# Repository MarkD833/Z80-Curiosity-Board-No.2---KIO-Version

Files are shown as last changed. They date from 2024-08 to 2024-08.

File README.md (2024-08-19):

# Zilog Z80 Curiosity Board #2 - The KIO Version

After my attempt to build a Z80 board met with reasonable success, I set my sights on a possible RetroDuino-Z80 board. This design is the pathfinder project with that goal in mind.

I wanted to have serial, parallel I/O and timer capability but aware of the space limitations, I decided to investigate the use of the Zilog Z80 KIO chip, or Z84C90 KIO as it's called.

This is a beast of a chip. It comes in a PLCC84 package which requires a big chunk of board space. The KIO combines the PIO, SIO  and CTC chips into one package.

The design still makes use of the PLCC44 Z80 CPU that I used previously.

## Description

The aim of this project is to provide the groundwork for a possible RetroDuino-Z80 board along the lines of my [RetroDuino-8085](https://github.com/MarkD833/RetroDuino-8085) board.

I'm hoping that this design can also run CP/M and I will be using Grant Searles excellent [web page](http://searle.x10host.com/cpm/index.html) as my starting point.

## Design

The design is fairly straightforward, using a 128Kb SRAM from my stash as well as a 64Kb EEPROM for non volatile storage. Only the lower 64Kb of SRAM is currently accessible.

I studied other designs that I came across and liked a concept that I came across whereby on startup, the whole of the ROM was copied into RAM and then the ROM disabled. The hardware was configured so that the ROM and the RAM both occupied the same 64Kb, but initially any read accessed would go to the ROM and any write accesses would go to the RAM. Once the ROM was copied into RAM (at the same addresses), the ROM would be disabled giving full read/write access to the RAM and the Z80 would continue to execute instructions as if nothing had happened.

The design uses simple logic chips to handle the address decoding, as well as the disabling of the ROM etc.

# The board layout

This is an annotated 3D view of the board generated by Kicad as it stands at v1.0.

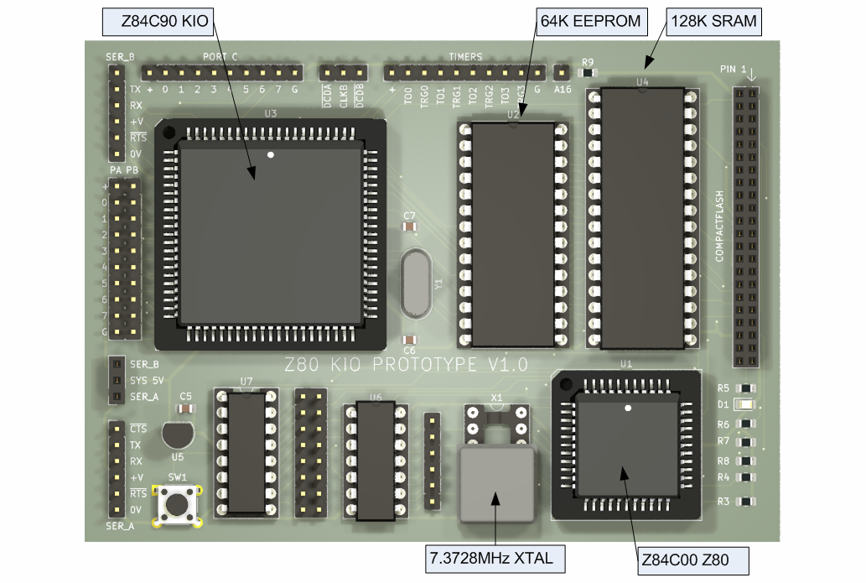
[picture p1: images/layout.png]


# Software

I adapted Dave Dunfields MONZ80 monitor program to work with this board. MONZ80 can be found on [Dave's website](https://dunfield.themindfactory.com/dnldsrc.htm) as part of the MONITORS.ZIP file. There is no documentation for the monitor but most of the commands are self explanatory.

The monitor code needs a slight tweek to reflect the address of the SIO registers within the KIO chip. My modified version of MONZ80 is in the code folder and has been edited to allow assembly using the free online assembler at [ASM80.COM](https://asm80.com) - select the Z80 CPU.

The code folder includes the assembler files to run CP/M from [Grant Searles web site](http://searle.x10host.com/cpm/index.html) but configured to assemble using the ASM80 online assembler. I've also included my instructions for loading CP/M onto the board, which are almost identical to Grants instructions.

# Known errors

* Nothing so far. 

# Conclusions

The board works as I had hoped it would. I need to develop routines for software SPI and also software I2C.

## License

This project is licensed under the GNU General Public License v3.0 - see the LICENSE.md file for details

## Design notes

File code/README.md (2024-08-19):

# Zilog Z80 Curiosity Board #2 - The KIO Version : Software

## The Z80 Monitor 
The MONZ80-RAM.ASM file contains a modified version of the excellent Z80 monitor called MONZ80 written by [Dave Dunfield](https://dunfield.themindfactory.com/). You can find the source code to the Z80 monitor along with monitors for other micros in the MONITORS.ZIP file on Dave's website. The monitor code needs a slight tweek to reflect the addresses of the SIO registers within the KIO chip. There's additional code to setup the KIO, handle the copying of the ROM into RAM and the disabling of the ROM.

MONZ80 can be assembled using the free online assembler at [ASM80.COM](https://asm80.com) - select the Z80 CPU.

I've not managed to locate a user manual for MONZ80 so I have included the user manual for MON85 as a guide to MONZ80.

# The Monitor and BASIC v4.7

## The Monitor (monitor.asm)

The simple monitor program is essentially Grants monitor program but modified to take into account the different addresses of the CompactFlash and SIO registers in my design. The monitor also copies itself into RAM and disables the ROM. The baud rate is also set to 57600 baud (rather than 115200 baud).

The main change is the use of SIO channel B. My Z80 KIO curiosity board doesn't have a hard wired clock into the SIO channel B TxCLKB & RxCLKB pins. Without a clock on TxCLKB, any byte in the TxB register will stay there forever and any code that waits for the Tx Buffer Empty bit to clear will hang forever.

As a result of this, the code expects a terminal connection on SIO channel A. I've added a constant called USE_SIOB which can be set to 0 to ignore SIO channel B or set to a 1 to also use SIO channel B. Setting USE_SIOB to a 1 will let the code detect a terminal on either SIO channel.

There are also some hard coded values that tell the monitor where to find BASIC. I've added a new value called BASSIZE which is the rough amount of ROM space that BASIC occupies. It is only needed when copying BASIC from ROM to RAM and I've set it to $2000.
 
## BASIC v4.7 (basic.asm)

The banner for this version of BASIC says that it is Z80 BASIC Ver 4.7b (c) 1978 by Microsoft. The assembler source has the phrase "NASCOM ROM BASIC Ver 4.7, (C) 1978 Microsoft".

I've modified this version of BASIC so that it can be assembled using ASM80. Other than that, the code is identical.

The Intel-Hex file can be programmed into the ROM at the same time as the monitor or it can be loaded into RAM using the monitor. 

# Installing CP/M

These are my notes for loading CP/M onto the board, which are almost identical to Grants instructions and include any modifications I may have done to his code.

## Step 1 - Formatting the CompactFlash drive

The formatting of the CompactFlash drive is done using the file FORM128.ASM (for 128Mb or larger CompactFlash cards). I've modified the CompactFlash registers to suit my KIO board and changed the directives so that the code can be assembled using ASM80.

Use the monitor to load the FORM128.HEX file and type G5000 to execute the code. The formatter should report back that it has created and formatted drives A to P.

## Step 2 - Installing CP/M

Installing CP/M involves 3 separate files: CP/M itself (CPM22.ASM), the CP/M BIOS (CBIOS128.ASM) and a small program to copy CP/M and the CP/M BIOS onto the CompactFlash card (PUTSYS.ASM).

* The CPM22.ASM file has been edited to change the directives so that the code can be assembled using ASM80.
* The CBIOS128.ASM file has been modified so the CompactFlash registers and SIO registers are correct for my KIO board. Directives have also been altered so that the code can be assembled using ASM80.
* The PUTSYS.ASM file has been modified so the CompactFlash registers are correct for my KIO board. Directives have also been altered so that the code can be assembled using ASM80.

Once the 3 files have been assembled, load each in turn from the monitor prompt. Then type G5000 to execute the PUTSYS program. This will copy CP/M and the CBIOS onto the CompactFlash card.

CP/M is now installed on the CompactFlash card. Reset the board and from the monitor prompt type X to boot CP/M, answering Y to the Boot CP/M prompt.

## Step 3 - Installing the downloader.

In order to transfer files to the CP/M system, a small application called DOWNLOAD.COM needs to be installed on the CP/M A: drive.

First, load CP/M off the CompactFlash card (X then Y in the monitor) and then reset the board. CP/M and the CBIOS are still in memory.

Download the file DOWNLOAD2.HEX. This file will be loaded into memory at address $4100. Then type GFFE8. This will execute a small piece of code that is part of the CBIOS. It will copy DOWNLOAD2.HEX from $4100 to $0100 and the run CP/M that is already in memory.

When the A> prompt appears, type SAVE 2 DOWNLOAD.COM. This will save 2 pages (2x 256 byte blocks, or 512 bytes) of data starting at address $0100 in memory to the file DOWNLOAD.COM on the A: drive.

At the A> prompt, you can type DIR <enter> to get a directory listing of drive A. You should see the file DOWNLOAD.COM.

## Step 4 - Transferring files to the CP/M system

You can read up on Grant Seales web page on how to use his packager program.

Before transferring the packaged files to the CP/M system, make sure that your terminal is set to use RTS/CTS handshaking as the serial routines in the CBIOS will use hardware handshaking to control the flow of data.

With CP/M running, download the file pkgCPM211Files.txt. This file is a package containing several CP/M programs: LOAD.COM, PIP.COM, STAT.COM, SUBMIT.COM, DDT.COM, DISPLAY.COM, DUMP.COM, ED.COM and ASM.COM. Most of these programs are detailed in the CP/M Operating System Manual.

You can also download the file pkgMBASIC.txt. This file is the CP/M version of BASIC-80 v5.21 by Microsoft.

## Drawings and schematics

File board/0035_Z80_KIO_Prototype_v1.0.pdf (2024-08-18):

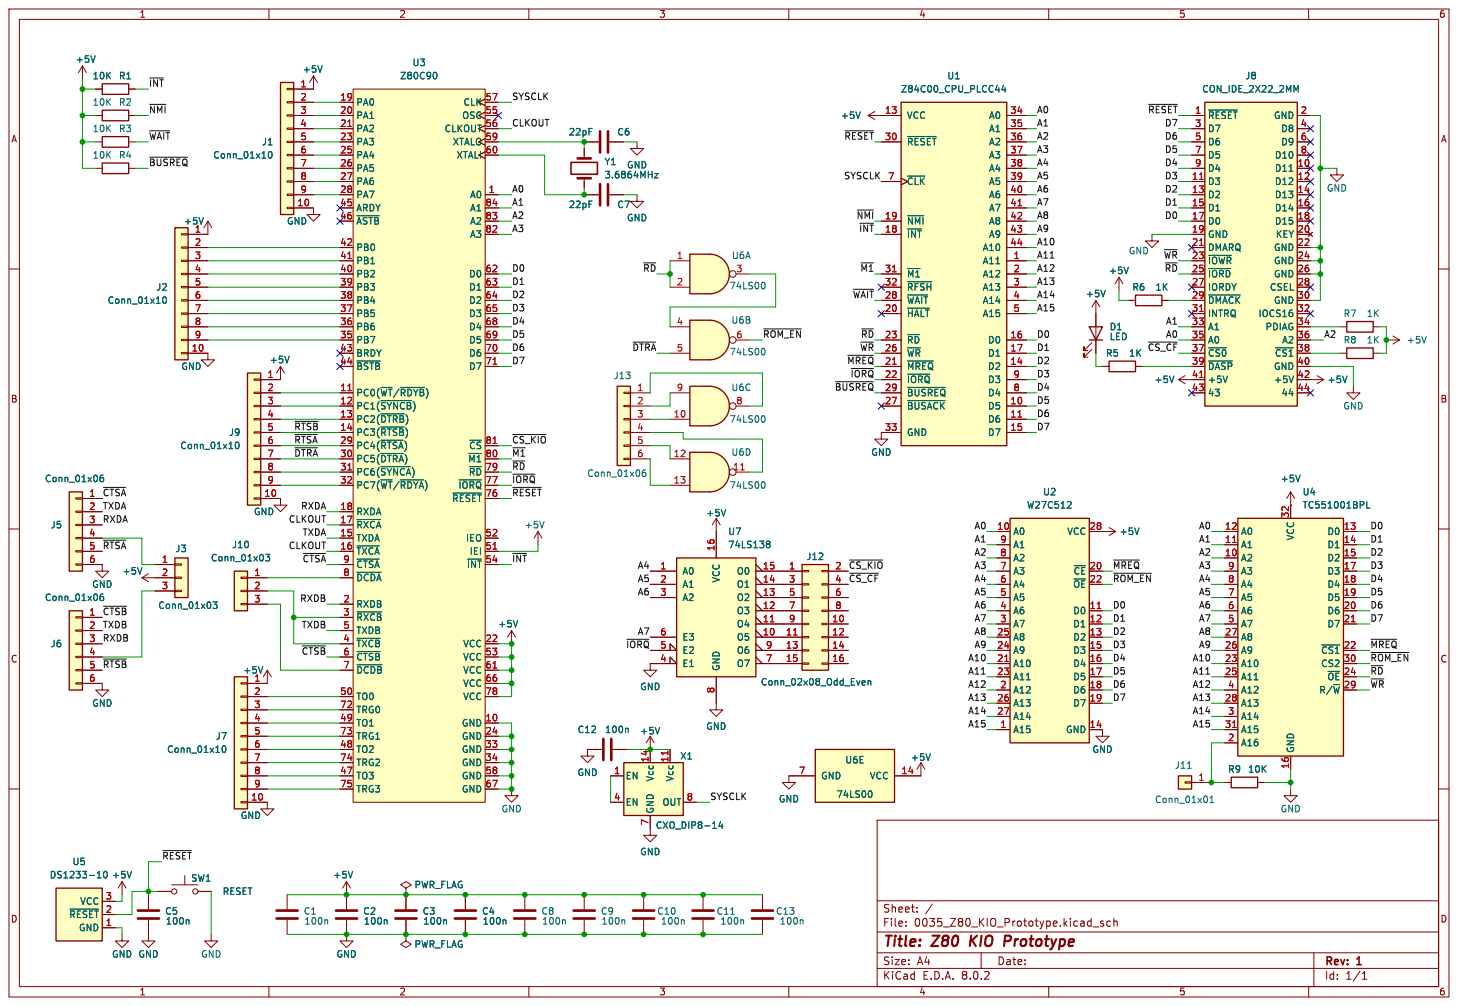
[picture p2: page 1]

File: 0035_Z80_KIO_Prototype.kicad_sch Sheet: /
Id: 1/1 Title: Z80 KIO Prototype

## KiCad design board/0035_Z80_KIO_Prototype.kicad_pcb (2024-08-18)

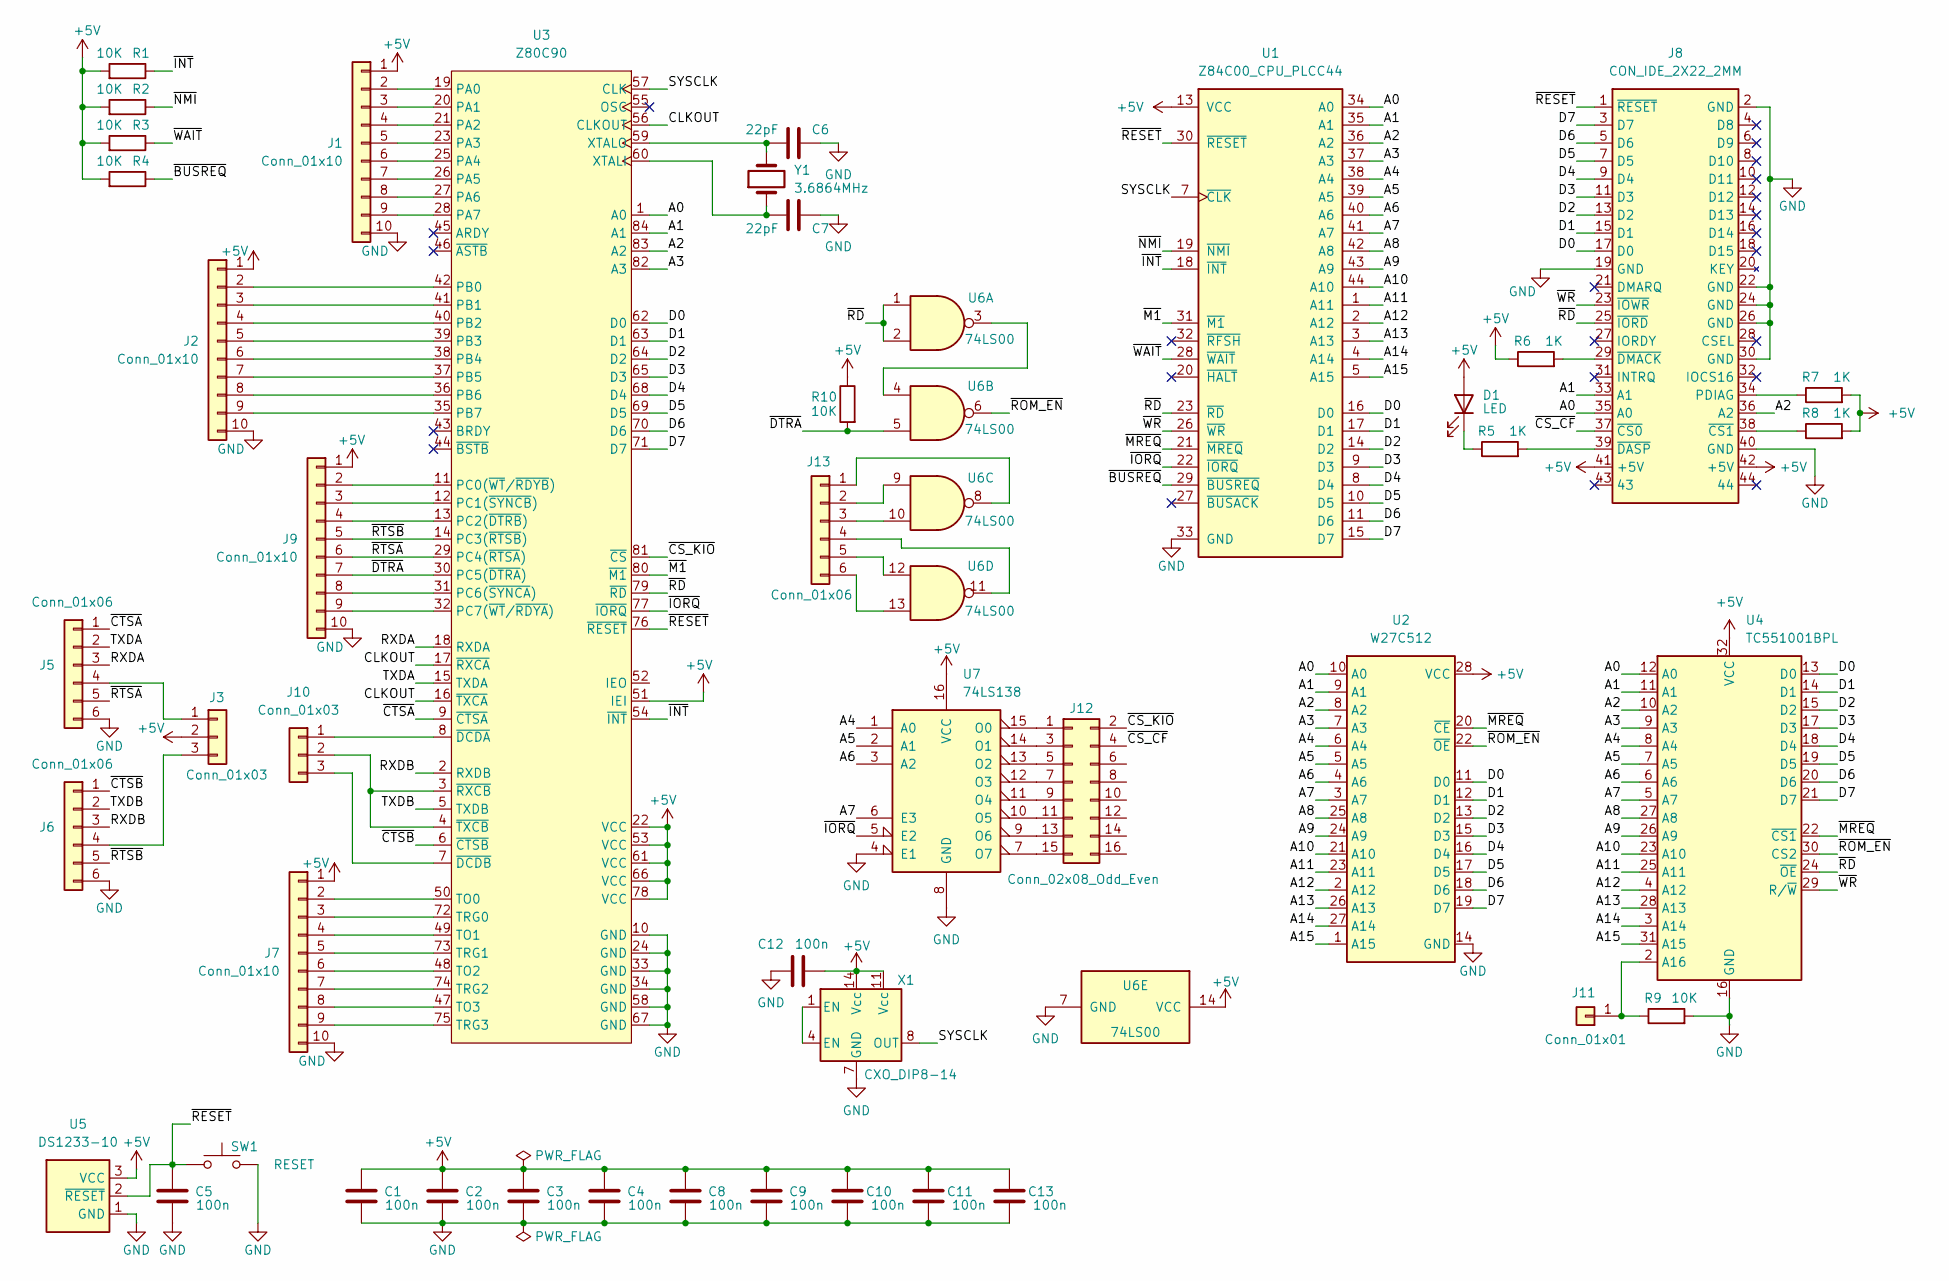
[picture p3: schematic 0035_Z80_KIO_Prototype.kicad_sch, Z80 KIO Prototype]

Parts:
C1, C2, C3, C4, C5, C8, C9, C10, C11, C12, C13: 100n; C_0805_2012Metric_Pad1.18x1.45mm_HandSolder
C6, C7: 22pF; C_0805_2012Metric_Pad1.18x1.45mm_HandSolder
D1: LED; LED_0805_2012Metric_Pad1.15x1.40mm_HandSolder
J1, J2, J7, J9: Conn_01x10; PinHeader_1x10_P2.54mm_Vertical
J3: Conn_01x03; PinSocket_1x03_P2.54mm_Vertical
J5, J6, J13: Conn_01x06; PinHeader_1x06_P2.54mm_Vertical
J8: CON_IDE_2X22_2MM; CompactFlashHeader_2x22_P2.00mm_Vertical
J10: Conn_01x03; PinHeader_1x03_P2.54mm_Vertical
J11: Conn_01x01; PinHeader_1x01_P2.54mm_Vertical
J12: Conn_02x08_Odd_Even; PinHeader_2x08_P2.54mm_Vertical
R1, R2, R3, R4, R9, R10: 10K; R_0805_2012Metric_Pad1.20x1.40mm_HandSolder
R5, R6, R7, R8: 1K; R_0805_2012Metric_Pad1.20x1.40mm_HandSolder
SW1: RESET; SW_TH_Tactile
U1: Z84C00_CPU_PLCC44; PLCC-44_THT-Socket
U2: W27C512; DIP-28_W15.24mm
U3: Z80C90; PLCC-84_THT-Socket
U4: TC551001BPL; DIP-32_W15.24mm_Socket
U5: DS1233-10; TO-92L_Inline
U6: 74LS00; DIP-14_W7.62mm_Socket
U7: 74LS138; DIP-16_W7.62mm_Socket
X1: CXO_DIP8-14; DIP-14_W7.62mm-XTAL_SOCKET
Y1: 3.6864MHz; Crystal_HC49-U_Vertical

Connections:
+5V: C1.2, C2.2, C3.2, C4.2, C8.2, C9.2, C10.2, C11.2, C12.2, C13.2, D1.2 (A), J1.1, J2.1, J3.2, J7.1, J8.41 (+5V), J8.42 (+5V), J9.1, R1.2, R2.2, R3.2, R4.2, R6.1, R7.2, R8.2, R10.1, U1.13 (VCC), U2.28 (VCC), U3.22 (VCC), U3.51 (IEI), U3.53 (VCC), U3.61 (VCC), U3.66 (VCC), U3.78 (VCC), U4.32 (VCC), U5.3 (VCC), U6.14 (VCC), U7.16 (VCC), X1.11 (Vcc), X1.14 (Vcc)
/A0: J8.35 (A0), U1.34 (A0), U2.10 (A0), U3.1 (A0), U4.12 (A0)
/A1: J8.33 (A1), U1.35 (A1), U2.9 (A1), U3.84 (A1), U4.11 (A1)
/A2: J8.36 (A2), U1.36 (A2), U2.8 (A2), U3.83 (A2), U4.10 (A2)
/A3: U1.37 (A3), U2.7 (A3), U3.82 (A3), U4.9 (A3)
/A4: U1.38 (A4), U2.6 (A4), U4.8 (A4), U7.1 (A0)
/A5: U1.39 (A5), U2.5 (A5), U4.7 (A5), U7.2 (A1)
/A6: U1.40 (A6), U2.4 (A6), U4.6 (A6), U7.3 (A2)
/A7: U1.41 (A7), U2.3 (A7), U4.5 (A7), U7.6 (E3)
/A8: U1.42 (A8), U2.25 (A8), U4.27 (A8)
/A9: U1.43 (A9), U2.24 (A9), U4.26 (A9)
/A10: U1.44 (A10), U2.21 (A10), U4.23 (A10)
/A11: U1.1 (A11), U2.23 (A11), U4.25 (A11)
/A12: U1.2 (A12), U2.2 (A12), U4.4 (A12)
/A13: U1.3 (A13), U2.26 (A13), U4.28 (A13)
/A14: U1.4 (A14), U2.27 (A14), U4.3 (A14)
/A15: U1.5 (A15), U2.1 (A15), U4.31 (A15)
/CLKOUT: U3.16 (~TXCA), U3.17 (~RXCA), U3.56 (CLKOUT)
/D0: J8.17 (D0), U1.16 (D0), U2.11 (D0), U3.62 (D0), U4.13 (D0)
/D1: J8.15 (D1), U1.17 (D1), U2.12 (D1), U3.63 (D1), U4.14 (D1)
/D2: J8.13 (D2), U1.14 (D2), U2.13 (D2), U3.64 (D2), U4.15 (D2)
/D3: J8.11 (D3), U1.9 (D3), U2.15 (D3), U3.65 (D3), U4.17 (D3)
/D4: J8.9 (D4), U1.8 (D4), U2.16 (D4), U3.68 (D4), U4.18 (D4)
/D5: J8.7 (D5), U1.10 (D5), U2.17 (D5), U3.69 (D5), U4.19 (D5)
/D6: J8.5 (D6), U1.11 (D6), U2.18 (D6), U3.70 (D6), U4.20 (D6)
/D7: J8.3 (D7), U1.15 (D7), U2.19 (D7), U3.71 (D7), U4.21 (D7)
/RXDA: J5.3, U3.18 (RXDA)
/RXDB: J6.3, U3.2 (RXDB)
/SYSCLK: U1.7 (~CLK), U3.57 (CLK), X1.8 (OUT)
/TXDA: J5.2, U3.15 (TXDA)
/TXDB: J6.2, U3.5 (TXDB)
/~BUSREQ: R4.1, U1.29 (~BUSREQ)
/~CS_CF: J8.37 (~CS0), J12.4
/~CS_KIO: J12.2, U3.81 (~CS)
/~CTSA: J5.1, U3.9 (~CTSA)
/~CTSB: J6.1, U3.6 (~CTSB)
/~DTRA: J9.7, R10.2, U3.30 (PC5(~DTRA)), U6.5
/~INT: R1.1, U1.18 (~INT), U3.54 (~INT)
/~IORQ: U1.22 (~IORQ), U3.77 (~IORQ), U7.5 (E2)
/~M1: U1.31 (~M1), U3.80 (~M1)
/~MREQ: U1.21 (~MREQ), U2.20 (~CE), U4.22 (~CS1)
/~NMI: R2.1, U1.19 (~NMI)
/~RD: J8.25 (~IORD), U1.23 (~RD), U3.79 (~RD), U4.24 (~OE), U6.1, U6.2
/~RESET: C5.2, J8.1 (~RESET), SW1.1, U1.30 (~RESET), U3.76 (~RESET), U5.2 (~RESET)
/~ROM_EN: U2.22 (~OE), U4.30 (CS2), U6.6
/~RTSA: J5.5, J9.6, U3.29 (PC4(~RTSA))
/~RTSB: J6.5, J9.5, U3.14 (PC3(~RTSB))
/~WAIT: R3.1, U1.28 (~WAIT)
/~WR: J8.23 (~IOWR), U1.26 (~WR), U4.29 (R/~W)
GND: C1.1, C2.1, C3.1, C4.1, C5.1, C6.2, C7.1, C8.1, C9.1, C10.1, C11.1, C12.1, C13.1, J1.10, J2.10, J5.6, J6.6, J7.10, J8.2 (GND), J8.19 (GND), J8.22 (GND), J8.24 (GND), J8.26 (GND), J8.30 (GND), J8.40 (GND), J9.10, R9.2, SW1.2, U1.33 (GND), U2.14 (GND), U3.10 (GND), U3.24 (GND), U3.33 (GND), U3.34 (GND), U3.58 (GND), U3.67 (GND), U4.16 (GND), U5.1 (GND), U6.7 (GND), U7.4 (E1), U7.8 (GND), X1.7 (GND)
unnamed: D1.1 (K), R5.1
unnamed: J1.2, U3.19 (PA0)
unnamed: J1.3, U3.20 (PA1)
unnamed: J1.4, U3.21 (PA2)
unnamed: J1.5, U3.23 (PA3)
unnamed: J1.6, U3.25 (PA4)
unnamed: J1.7, U3.26 (PA5)
unnamed: J1.8, U3.27 (PA6)
unnamed: J1.9, U3.28 (PA7)
unnamed: J2.2, U3.42 (PB0)
unnamed: J2.3, U3.41 (PB1)
unnamed: J2.4, U3.40 (PB2)
unnamed: J2.5, U3.39 (PB3)
unnamed: J2.6, U3.38 (PB4)
unnamed: J2.7, U3.37 (PB5)
unnamed: J2.8, U3.36 (PB6)
unnamed: J2.9, U3.35 (PB7)
unnamed: J3.1, J5.4
unnamed: J3.3, J6.4
unnamed: J7.2, U3.50 (TO0)
unnamed: J7.3, U3.72 (TRG0)
unnamed: J7.4, U3.49 (TO1)
unnamed: J7.5, U3.73 (TRG1)
unnamed: J7.6, U3.48 (TO2)
unnamed: J7.7, U3.74 (TRG2)
unnamed: J7.8, U3.47 (TO3)
unnamed: J7.9, U3.75 (TRG3)
unnamed: J8.34 (PDIAG), R7.1
unnamed: J8.38 (~CS1), R8.1
unnamed: J8.39 (~DASP), R5.2
unnamed: J8.29 (~DMACK), R6.2
unnamed: J9.2, U3.11 (PC0(~WT/~RDYB))
unnamed: J9.3, U3.12 (PC1(~SYNCB))
unnamed: J9.4, U3.13 (PC2(~DTRB))
unnamed: J9.8, U3.31 (PC6(~SYNCA))
unnamed: J9.9, U3.32 (PC7(~WT/~RDYA))
unnamed: J10.1, U3.8 (~DCDA)
unnamed: J10.2, U3.3 (~RXCB), U3.4 (~TXCB)
unnamed: J10.3, U3.7 (~DCDB)
unnamed: J11.1, R9.1, U4.2 (A16)
unnamed: J12.1, U7.15 (O0)
unnamed: J12.3, U7.14 (O1)
unnamed: J12.5, U7.13 (O2)
unnamed: J12.7, U7.12 (O3)
unnamed: J12.9, U7.11 (O4)
unnamed: J12.11, U7.10 (O5)
unnamed: J12.13, U7.9 (O6)
unnamed: J12.15, U7.7 (O7)
unnamed: J13.1, U6.8
unnamed: J13.2, U6.9
unnamed: J13.3, U6.10
unnamed: J13.4, U6.11
unnamed: J13.5, U6.12
unnamed: J13.6, U6.13
unnamed: C7.2, U3.60 (XTALI), Y1.1
unnamed: C6.1, U3.59 (XTALO), Y1.2
unnamed: U6.3, U6.4
unnamed: X1.1 (EN), X1.4 (EN)

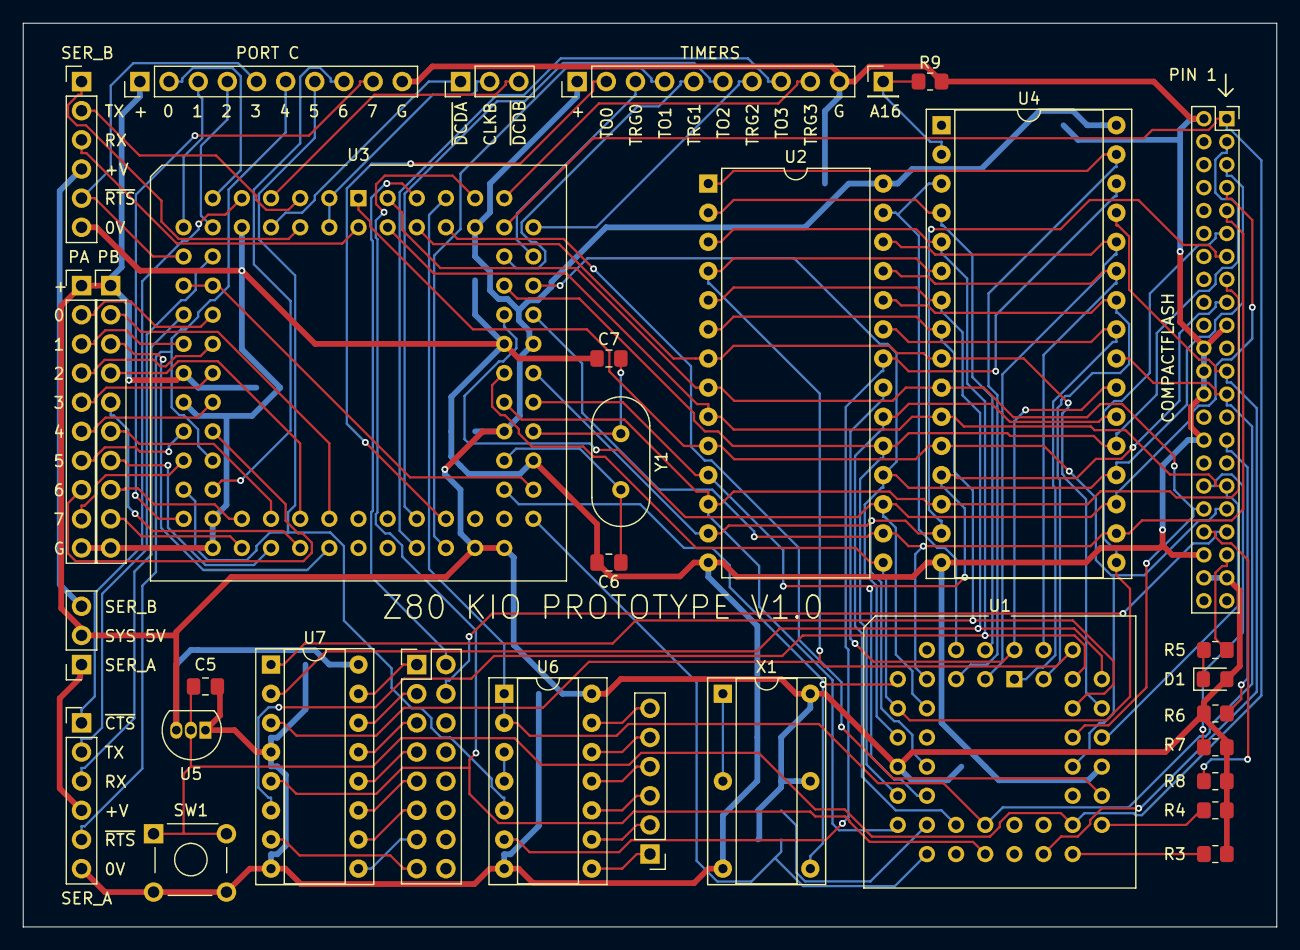
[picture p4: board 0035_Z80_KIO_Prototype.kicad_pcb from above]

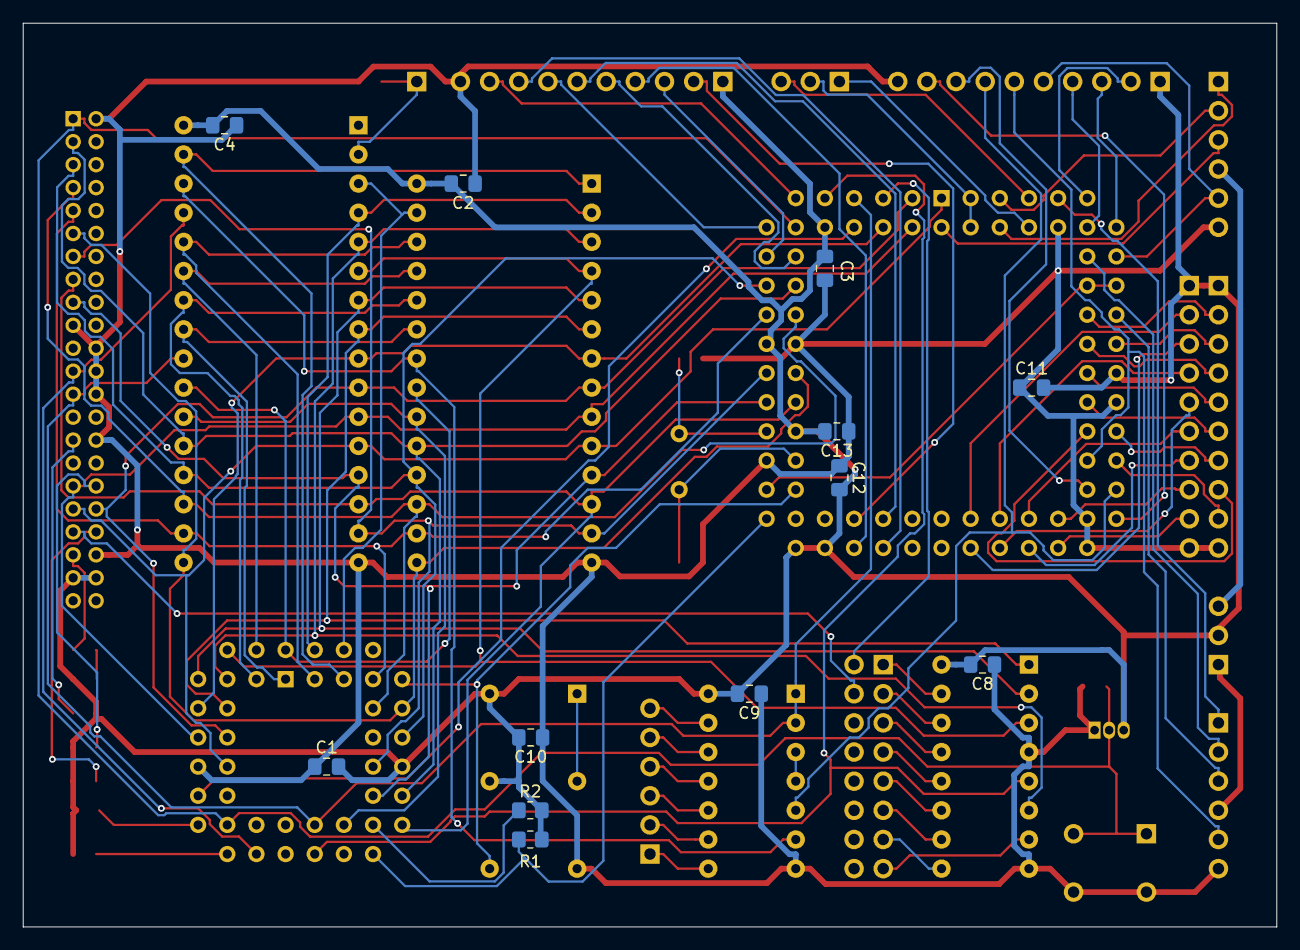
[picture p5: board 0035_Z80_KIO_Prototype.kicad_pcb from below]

Board: 2 copper layers, 109.2 x 78.7 mm, 45 parts (12 on the bottom side), 108 nets.
